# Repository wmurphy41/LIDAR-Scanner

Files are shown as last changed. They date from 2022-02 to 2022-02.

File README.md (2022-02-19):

# 3D Lidar Scanner
 3D Printed 3D Lidar Scanner

 ## Project Overview

 #### References and Attributions
 - Design for turntable derived from this [hand-cranked table](https://bbprojects.technology/collections/stl-fusion-360-source-files/products/fully-3d-printable-turntable-files)

 #### Background Information

## Files
Content of the project folders:
- **code** - Arduino and processing code
- **physical** - STL Files
- **circuits** - electronic circuit design
- **media** - pictures and video of project

## Bill of Materials
- 1x Arduino nano

## Installation
Instructions for building the printed components, electronics, software, and assembly of the 3D Scanner

#### Printed Components
Print all components in PLA.  Don't use supports, rafts, etc for the gears, bearing, or connectors.
Print the plumbing at 45 deg for better structural integrity.

| Component | Count | Color |
| --- | ----: | ----- |
| big gear | 1 | white |
| leg | 3 | white |
| motor base | 1 | white |
| motor mount | 1 | white |
| plate | 1 | black |
| shaft-connector | 1 | white |
| slide bearing | 1 | white |
| small gear | 1 | white |

#### Electronics
1. Hack the stepper motors.  The 28BYJ-48 stepper motors are unipolar and the
A4988 driver only works with bipolar motors.  Take the red wire out of the connector,
cut it near the motor and discard.  Reorder the wires in the connector so that
are in order orange, yellow, pink, blue, reading left to right when looking at
the flat side of the connector.  More info on this step [here](https://www.instructables.com/28BYJ-48-5V-Stepper-Motor-and-A4988-Driver/)  I ignored adjusting
the current potentiometer.
2. Build prototype board based on circuit diagrams.  Pins.h matches the pin
configuration of the prototype circuit diagram.  Breadboard diagram used different pins.

#### Code

## Assembly

## Usage
Operating instructions

## Ideas for Future Enhancements

## Contributing
- Pull requests are welcome. For major changes, please open an issue first to discuss what you would like to change.
- Please make sure to test updates as appropriate.

## License
[MIT](https://choosealicense.com/licenses/mit/)

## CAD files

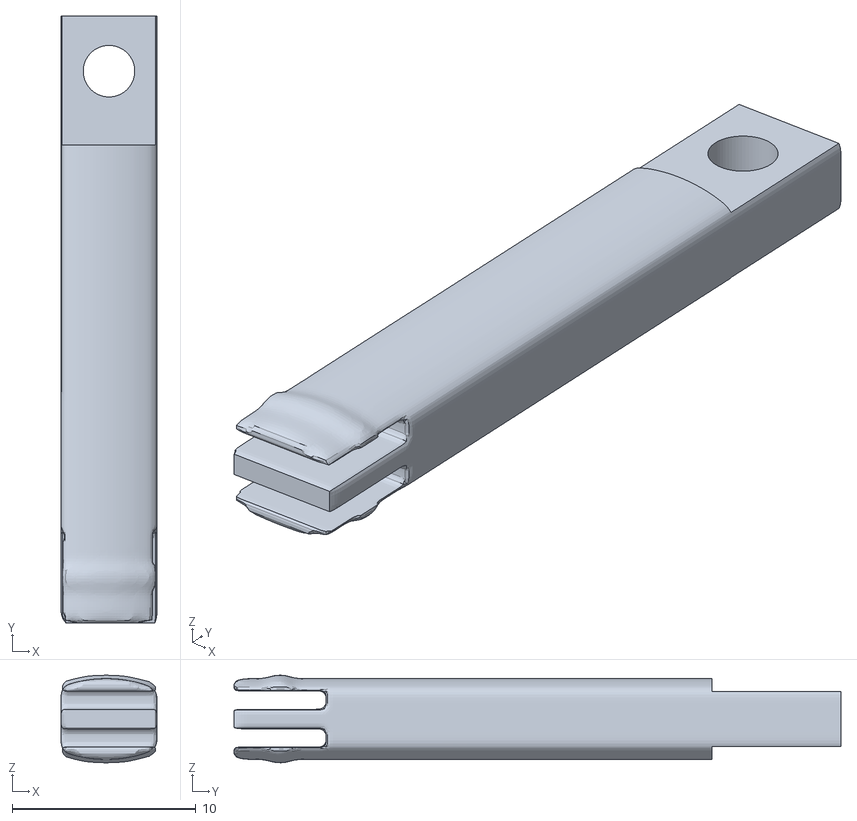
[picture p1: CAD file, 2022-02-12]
physical/motor mount.stl
5.24 x 33.0 x 4.76

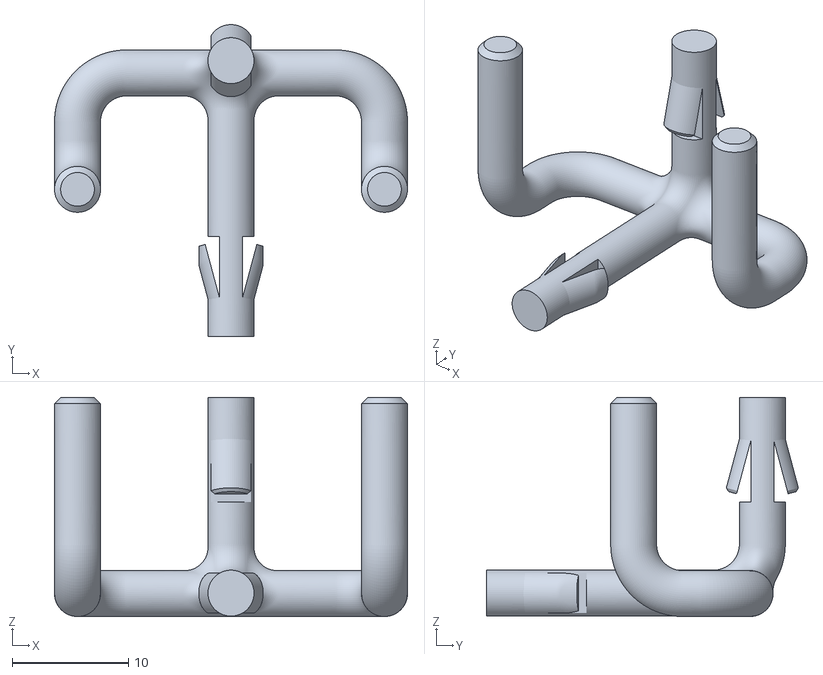
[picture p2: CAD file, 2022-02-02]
physical/plumbing.stl
30.3 x 26.8 x 18.8

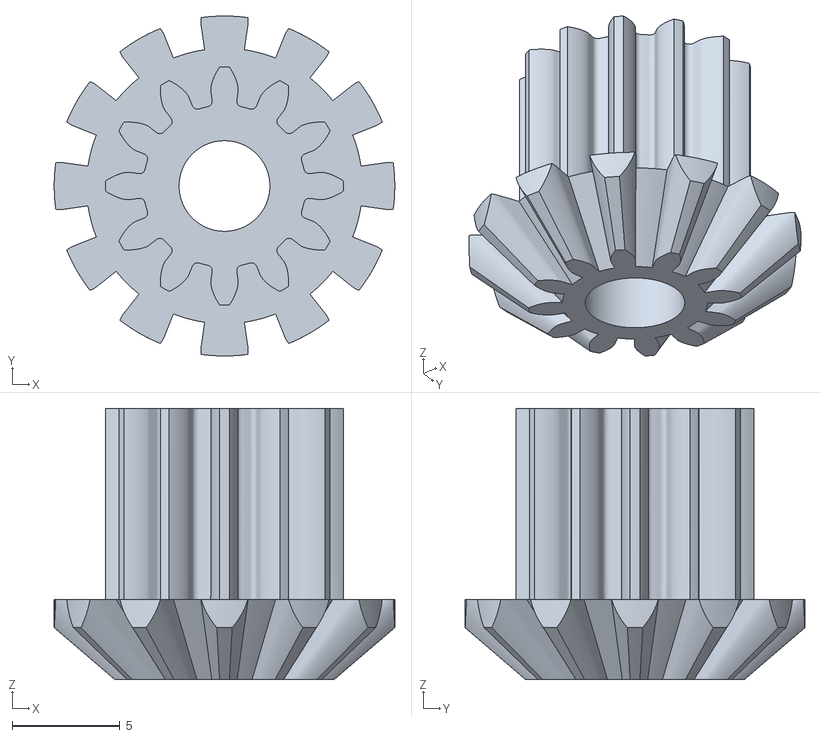
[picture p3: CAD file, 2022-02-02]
physical/small gear.stl
15.8 x 15.8 x 12.6

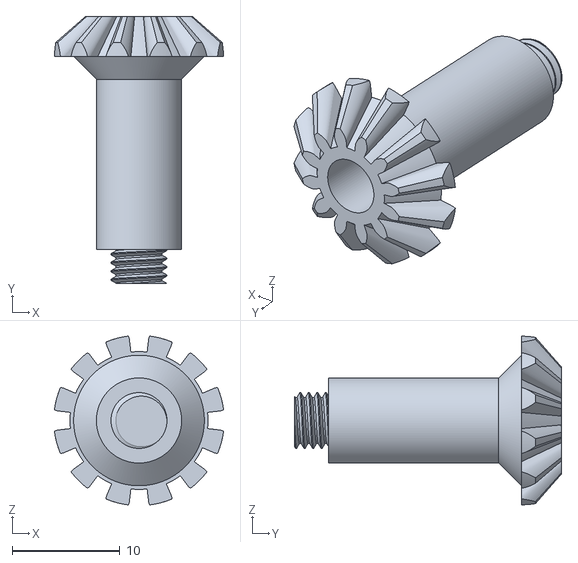
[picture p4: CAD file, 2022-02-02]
physical/big gear.stl
15.7 x 24.8 x 15.7

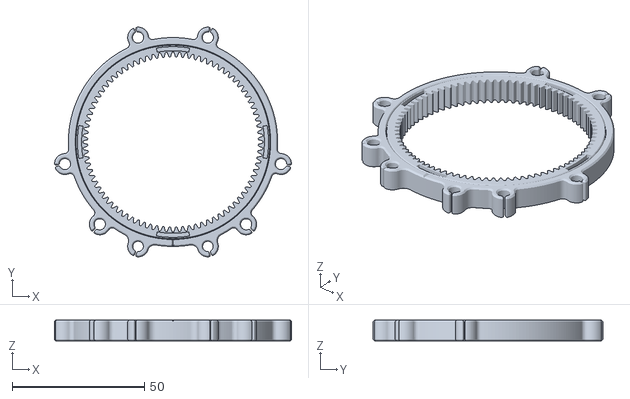
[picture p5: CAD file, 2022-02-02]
physical/slide bearing.stl
89.7 x 86.9 x 7.90

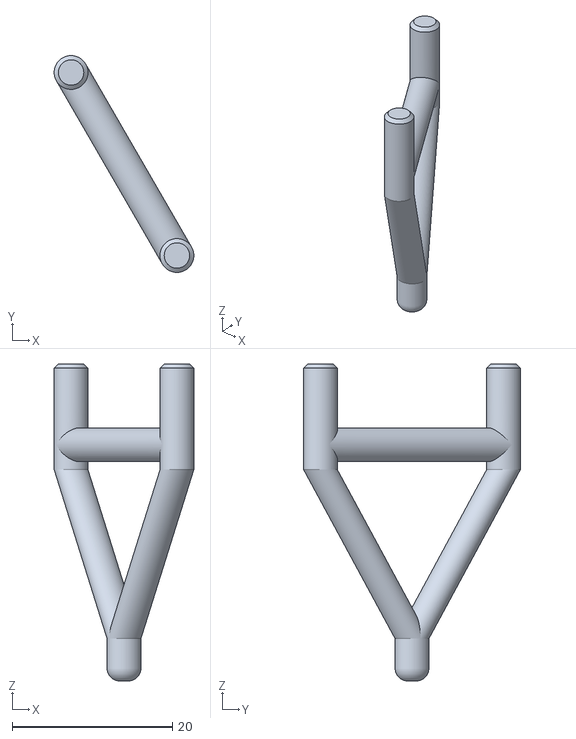
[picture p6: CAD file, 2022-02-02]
physical/leg.stl
17.4 x 27.0 x 39.5

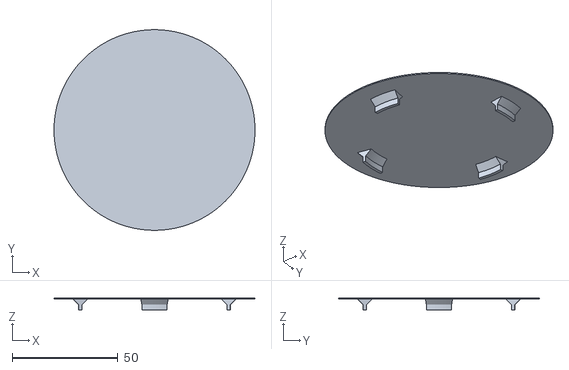
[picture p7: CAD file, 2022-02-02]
physical/plate.stl
95.0 x 94.8 x 5.80

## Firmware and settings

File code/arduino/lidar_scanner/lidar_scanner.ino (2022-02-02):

// Lidar Scanner Sketch
// 
// Let's you manually position the scanner to a start position and
// then kick off an automatic scan around that start point.

#include "LidarScanner.hpp"
#include <Geometry.h>
#include <ArduinoSTL.h>
#include <map>


// Pin settings
#define SERVO_HORIZ_PIN 2
#define SERVO_VERT_PIN 3

// Physical configuration of servo
#define MIN_POS_H  20        
#define MAX_POS_H 160      
#define MIN_POS_V  -20        
#define MAX_POS_V 125      
#define SCAN_WINDOW_DEG   30 // Degrees
#define MAX_WINDOW_DEPTH 100 // CM
#define SCAN_STEP_DEG 5

// Global Variables

// Mapping for the loop commands
std::map<char, LidarScanner::directions_t> dir_cmds ;
std::map<char, LidarScanner::scan_t> scan_cmds ;

LidarScanner scanner(SERVO_HORIZ_PIN, SERVO_VERT_PIN,
					            MIN_POS_H, MAX_POS_H,
					            MIN_POS_V, MAX_POS_V) ; 
                 

// -------------------------------
// Setup code
// -------------------------------
void setup() {
	Serial.begin(9600);

  dir_cmds.insert(std::pair<char, LidarScanner::directions_t>('U', LidarScanner::up)) ;
  dir_cmds.insert(std::pair<char, LidarScanner::directions_t>('D', LidarScanner::down)) ;
  dir_cmds.insert(std::pair<char, LidarScanner::directions_t>('L', LidarScanner::left)) ;
  dir_cmds.insert(std::pair<char, LidarScanner::directions_t>('R', LidarScanner::right)) ;

  scan_cmds.insert(std::pair<char, LidarScanner::scan_t>('H', LidarScanner::horizontal)) ;
  scan_cmds.insert(std::pair<char, LidarScanner::scan_t>('V', LidarScanner::vertical)) ;
  scan_cmds.insert(std::pair<char, LidarScanner::scan_t>('S', LidarScanner::spiral)) ;

  Serial << "Moving scanner to initial position...\n" ;
  scanner.setup() ;  // Initialize and move to start pos

 }


// -------------------------------
// Loop Logic
// -------------------------------
void loop() {

  int incomingByte = 0 ;
  if (Serial.available() > 0)
    incomingByte = Serial.read() ;

  if (scanner.getScanMode() == LidarScanner::manual) {

    if (! incomingByte) return ;

    if (dir_cmds.find(incomingByte) != dir_cmds.end()) {
      scanner.moveServosRel(dir_cmds[incomingByte], SCAN_STEP_DEG) ;
      
      Serial << "Manual step " << (char) incomingByte << "\n" ;
      Serial << "New position: h = " << scanner.getHorizontalPos() ;
      Serial <<             ", v = " << scanner.getVerticalPos() << "\n" ;
      Serial << "Return: distance = " << scanner.getReturnDistance() << " cm \n" ;
    }
      
    // Initiate a scan
    else if (scan_cmds.find(incomingByte) != scan_cmds.end()) {
    scanner.startAutoScan(scan_cmds[incomingByte], SCAN_WINDOW_DEG, MAX_WINDOW_DEPTH) ;
    Serial << "Starting auto scan type: " << (char)incomingByte << "\n" ;
    }
    
    else 
     Serial << "Unknown command " << (char)incomingByte << "\n";

    return ;
  }
 
  // Autoscan mode: 
  // 1.) check if user is breaking; 
  // 2.) print current position
  // 3.) Step to next postion, cancel autoscan, if done 
  if (incomingByte == 'B') {
      Serial << "Breaking autoscan. \n" ;
      scanner.stopAutoScan() ;           
      return ;
  }
  
  Point p = scanner.getReturnPoint() ;
  Serial.println(String(-p.X(), 5) + " " + String(p.Y(), 5) + " " + String(-p.Z(), 5) ) ;
  
  bool continue_scan = scanner.autoScanStep() ;
  
  if (! continue_scan) {
      Serial << "Autoscan completed. \n " ;
      scanner.stopAutoScan() ;
  }

  return ;
}

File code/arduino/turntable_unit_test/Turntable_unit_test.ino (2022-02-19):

/*
 *  Turntable Unit Test
 *
 *  Exercises the methods of the Turntable class.
 */

#include "Turntable.h"
#include "pins.h"         // pin assignments


// Logic constants
const int LOOP_TIMER = 5000 ;     // Time between switching modes (5s)
enum TestModes { turn_f, turn_b, pause_1, turn_s1, turn_s2, turn_s3, pause } ;

// Globals
Turntable turntable(STEP_PIN, DIR_PIN, ENABLE_PIN) ;


/* Setup()
 *
 * Start serial port
 */
void setup () {
    Serial.begin(57600);
    Serial.println("Starting setup...") ;

    Serial.println("...completed setup.") ;
}

/*
 * loop()
 * - Every 15 seconds cycle to the next test mode.
 * - Call the turntable run funcion to step the turntable
 */
void loop () {
  static TestModes test_mode = pause ;
  static long timeLastClick = -LOOP_TIMER ;  // Start testing on first pass

  // Every 15 seconds cycle through to next test mode
  if ( millis() - timeLastClick > LOOP_TIMER ) {
    timeLastClick = millis() ;
    test_mode = nextTest(test_mode) ;

    switch(test_mode) {
      case turn_f :
        Serial.println("Turning forward.") ;
        turntable.turnForward() ;
        break ;
      case turn_b :
        Serial.println("Turning backward.") ;
        turntable.turnBackward() ;
        break ;
      case turn_s1 :
      case turn_s2 :
      case turn_s3 :
       Serial.println("Turning one slice.") ;
        turntable.turnOneSlice() ;
        break ;
      default :
        Serial.println("Stopping.") ;
        turntable.stopTurn() ;
    }
  }

  // Step the turntable.
  turntable.run() ;
}

// Helper function for cycling through the test modes
int nextTest(int tm) {
  if (tm == pause)
    tm = turn_f ;
  else
    tm++ ;
  return tm ;
} 

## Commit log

2022-02-02 Baseline build
    Starting point... Scanner works independently with a breadboard. Processing code creates point cloud.
    [Turntable - complete.3mf, big gear - 4in.stl, handle - 4in.stl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]
2022-02-12 Turntable created
    Updated physical design to include base, mount, and connector for stepper motor.
    [Turntable - complete.3mf, big gear - 4in.stl, big gear.stl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]
2022-02-19 Update lidar_scanner_breadboard.fzz
    Missed in turntable update.
    [lidar_scanner_breadboard.fzz]
